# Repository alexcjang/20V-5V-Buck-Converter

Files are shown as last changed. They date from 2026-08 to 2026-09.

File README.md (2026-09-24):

# 20V-5V Buck Converter

## Overview
Goal: fully functioning buck converter that can step down voltage from 20V to 5V with less than 5% ripple. Custom PCB designed with KiCad, assembled with capacitors, inductors, gate driver, MOSFETs, and Op-Amp.

## Key Results
- Peak efficiency: ~85% driving 5W load
- Output ripple: <40mV

## Design
- **Topology:** Asynchronous Buck
- **Duty Cycle:** 0.25 to step down voltage by x4
- **PCB:** 2-layer, component selection to trade off between size and efficiency

## What I'd Change
This was my first real power converter design, which helped me practice circuit design, component selection, and understanding power converters. If I could redo this project, I would definitely use a 4 layer board to optimize my layout a lot and cut down on parasitics from excess loop length. I would also simulate my system first in PLECS or SPICE adjacent software to gain a better understanding of what specs I am targeting and how to achieve them.

## Media


## Tools
LTSpice, KiCAD, Oscilloscope

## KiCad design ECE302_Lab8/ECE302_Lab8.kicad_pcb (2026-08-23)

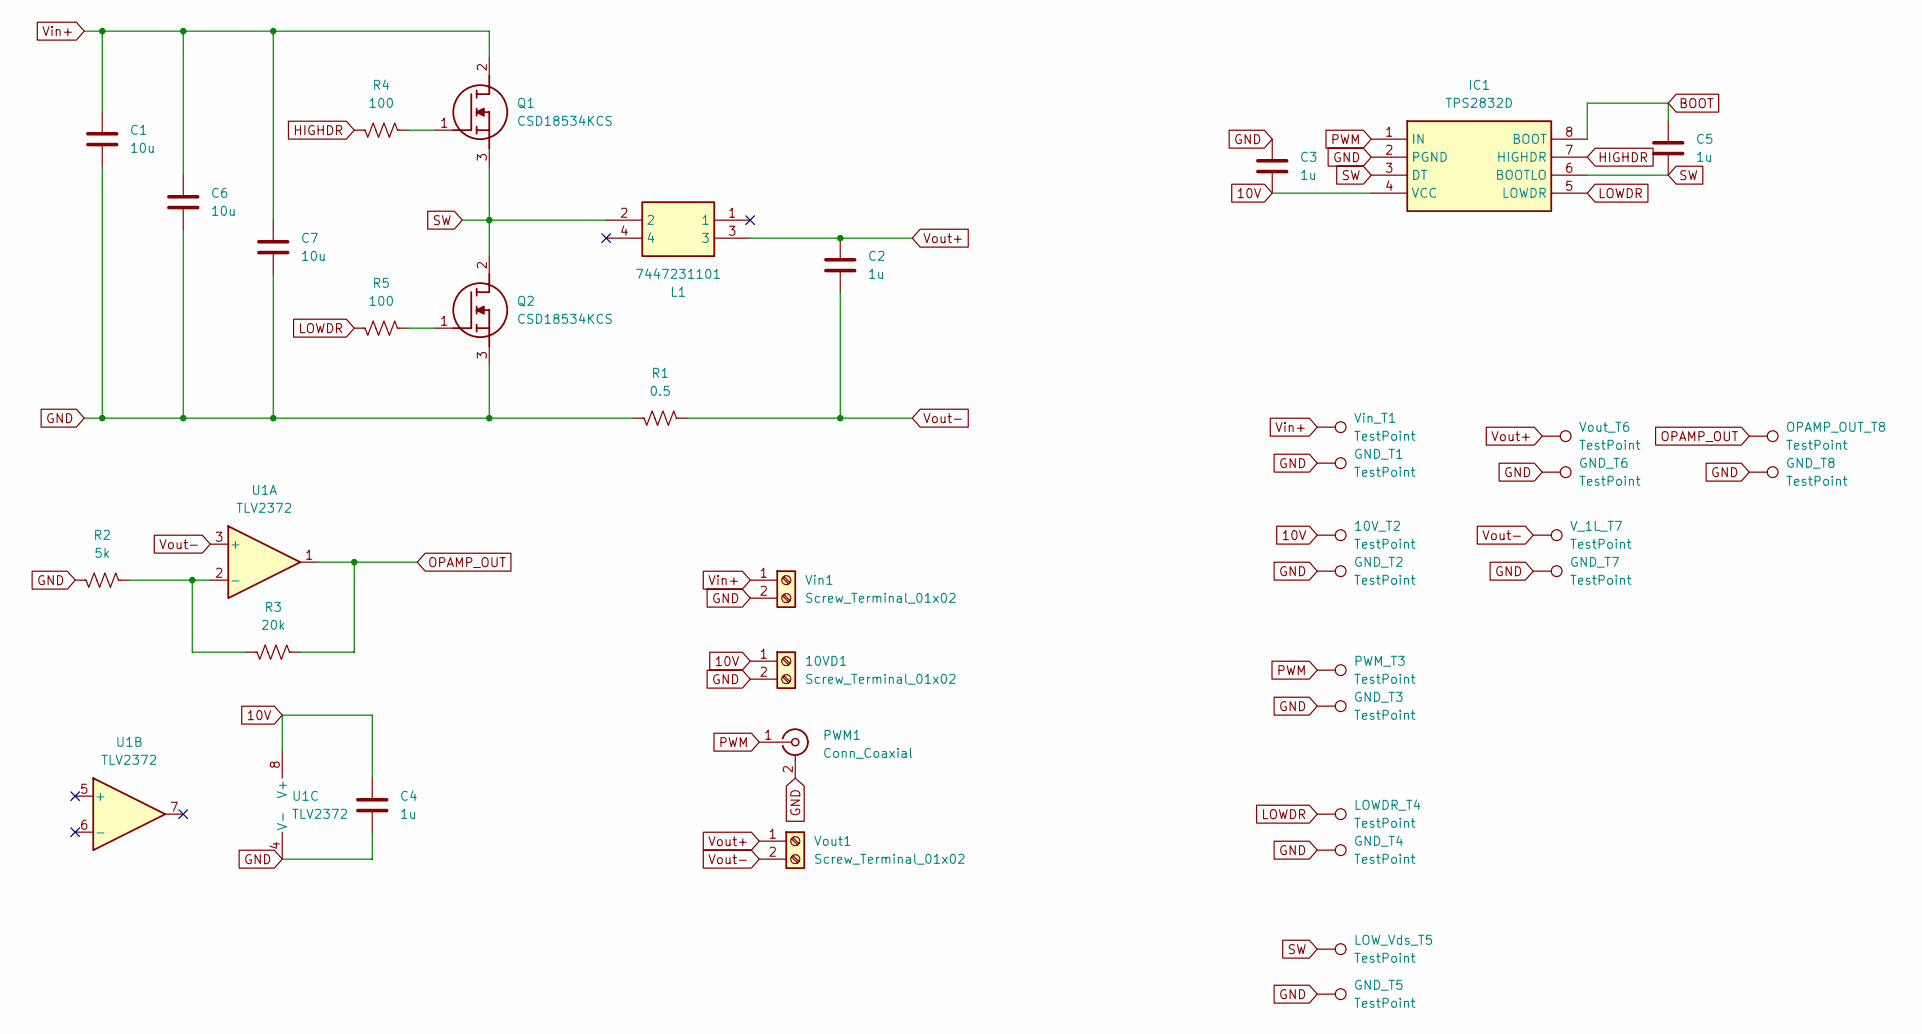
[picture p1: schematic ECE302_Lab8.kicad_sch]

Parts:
10VD1: Screw_Terminal_01x02; PhoenixContact_MSTBA_2,5_2-G_1x02_P5.00mm_Horizontal
10V_T2: TestPoint; TestPoint_Keystone_5010-5014_Multipurpose
C1, C6, C7: 10u; C_Disc_D3.8mm_W2.6mm_P2.50mm
C2, C3, C4, C5: 1u; C_Disc_D3.8mm_W2.6mm_P2.50mm
GND_T1, GND_T2, GND_T3, GND_T4, GND_T5, GND_T6, GND_T7, GND_T8: TestPoint; TestPoint_Keystone_5010-5014_Multipurpose
IC1: TPS2832D; SO-8_3.9x4.9mm_P1.27mm; Manufacturer_Part_Number TPS2832D; Mouser Part Number 595-TPS2832D
L1: 7447231101; Manufacturer_Part_Number 7447231101
LOWDR_T4: TestPoint; TestPoint_Keystone_5010-5014_Multipurpose
LOW_Vds_T5: TestPoint; TestPoint_Keystone_5010-5014_Multipurpose
OPAMP_OUT_T8: TestPoint; TestPoint_Keystone_5010-5014_Multipurpose
PWM1: Conn_Coaxial; BNC_Amphenol_B6252HB-NPP3G-50_Horizontal
PWM_T3: TestPoint; TestPoint_Keystone_5010-5014_Multipurpose
Q1, Q2: CSD18534KCS; TO-220-3_Vertical; Manufacturer_Part_Number CSD18534KCS; Mouser Part Number 595-CSD18534KCS
R1: 0.5; R_Axial_DIN0922_L20.0mm_D9.0mm_P30.48mm_Horizontal
R2: 5k; R_Axial_DIN0207_L6.3mm_D2.5mm_P10.16mm_Horizontal
R3: 20k; R_Axial_DIN0207_L6.3mm_D2.5mm_P10.16mm_Horizontal
R4, R5: 100; R_Axial_DIN0207_L6.3mm_D2.5mm_P10.16mm_Horizontal
U1: TLV2372; SO-8_3.9x4.9mm_P1.27mm
V_1L_T7: TestPoint; TestPoint_Keystone_5010-5014_Multipurpose
Vin1: Screw_Terminal_01x02; PhoenixContact_MSTBA_2,5_2-G_1x02_P5.00mm_Horizontal
Vin_T1: TestPoint; TestPoint_Keystone_5010-5014_Multipurpose
Vout1: Screw_Terminal_01x02; PhoenixContact_MSTBA_2,5_2-G_1x02_P5.00mm_Horizontal
Vout_T6: TestPoint; TestPoint_Keystone_5010-5014_Multipurpose

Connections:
10V: 10VD1.1, 10V_T2.1, C3.2, C4.1, IC1.4 (VCC), U1.8 (V+)
BOOT: C5.1, IC1.8 (BOOT)
GND: 10VD1.2, C1.2, C3.1, C4.2, C6.2, C7.2, GND_T1.1, GND_T2.1, GND_T3.1, GND_T4.1, GND_T5.1, GND_T6.1, GND_T7.1, GND_T8.1, IC1.2 (PGND), PWM1.2 (Ext), Q2.3 (S), R1.1, R2.1, U1.4 (V-), Vin1.2
HIGHDR: IC1.7 (HIGHDR), R4.1
LOWDR: IC1.5 (LOWDR), LOWDR_T4.1, R5.1
unnamed: Q1.1 (G), R4.2
unnamed: Q2.1 (G), R5.2
unnamed: R2.2, R3.1, U1.2 (-)
OPAMP_OUT: OPAMP_OUT_T8.1, R3.2, U1.1
PWM: IC1.1 (IN), PWM1.1 (In), PWM_T3.1
SW: C5.2, IC1.3 (DT), IC1.6 (BOOTLO), L1.2, LOW_Vds_T5.1, Q1.3 (S), Q2.2 (D)
Vin+: C1.1, C6.1, C7.1, Q1.2 (D), Vin1.1, Vin_T1.1
Vout+: C2.1, L1.3, Vout1.1, Vout_T6.1
Vout-: C2.2, R1.2, U1.3 (+), V_1L_T7.1, Vout1.2

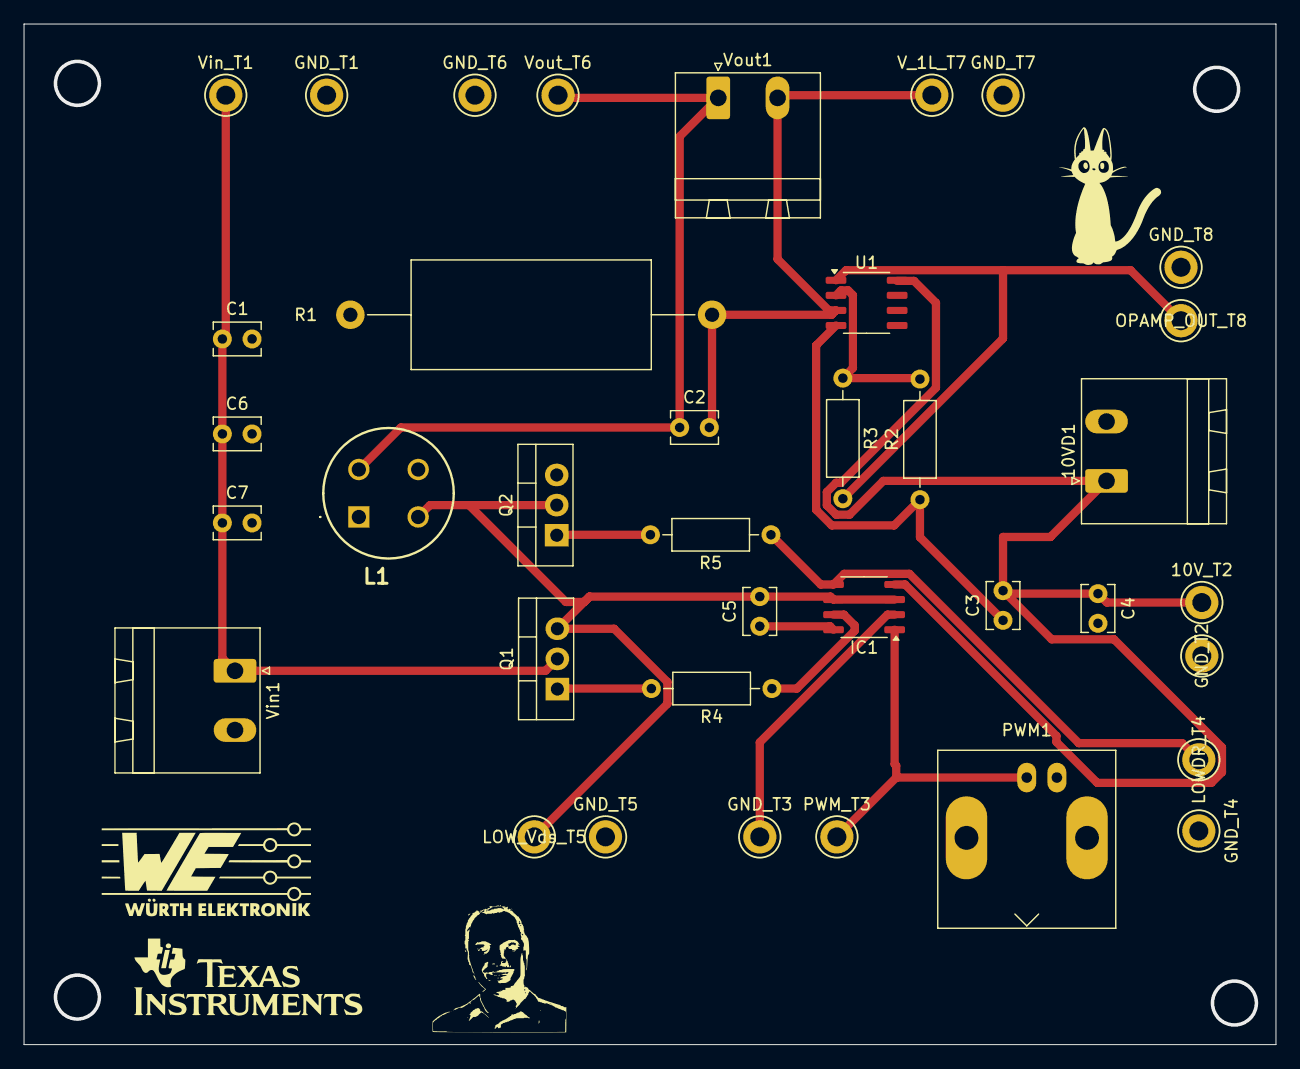
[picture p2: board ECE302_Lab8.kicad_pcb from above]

Board: 2 copper layers, 105.5 x 86.0 mm, 37 parts (0 on the bottom side), 14 nets.
